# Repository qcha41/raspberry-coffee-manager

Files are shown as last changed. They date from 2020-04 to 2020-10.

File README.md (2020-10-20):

# Raspberry Coffee Manager

This is a raspberry project dedicated to the management of a shared coffee caps stock in a group through a user-friendly touchscreen interface and a RFID tag reader.

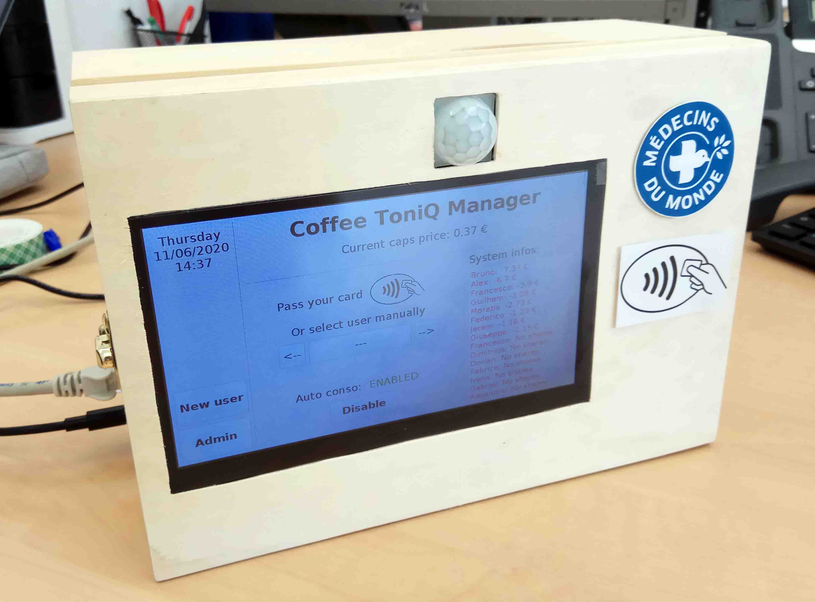
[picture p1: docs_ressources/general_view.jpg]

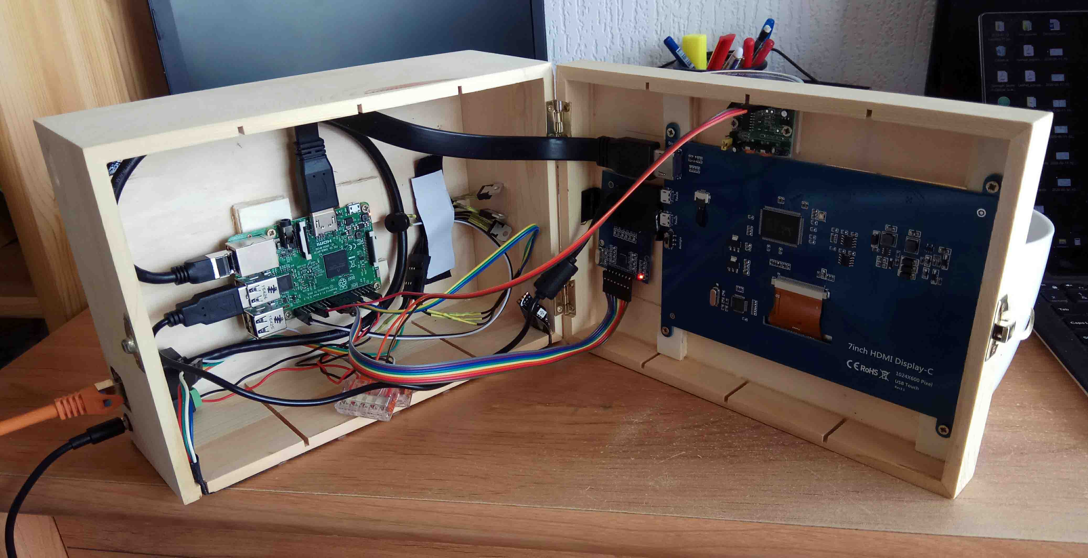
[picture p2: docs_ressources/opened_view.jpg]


## Features

- **User accounts**: The basic idea of this system is that users notify the raspberry manager each time they take a coffee caps from the group stock. This is done simply by passing their personal RFID tags near an integrated reader, or by selecting their name on the main screen. The corresponding caps price is then deducted from their personal virtual account. The users can recharge their accounts by putting some money in a common group box (or any other method decided in the group), and notify themselves this recharge in the account panel of the graphical interface. In this panel, they can also review the activity of their account day by day, change their name, link their account with another RFID tag, etc. Users also receive email notifications when their accounts are negative.

- **Admin panel**: The person in charge of managing the coffee in the group has access to a private admin panel, either by using its admin RFID tag, or by entering a password in the graphical interface. From that panel, the admin can review system operations (users recharges, ...), notify a group caps purchase, a supply purchase, or that a few caps are missing in the stock, etc.

- **Dynamical caps price**: The system thus know how many caps have been added in the stock by the admin, and how many were taken by the users. The caps price deducted from the virtual accounts is then dynamic, and is simply calculated by dividing the remaining system charges by the remaining number of caps.

- **Charities donations**: More than just managing a caps stock, this project is also a tool to raise money for charities in a group easily. In their account panel, users can indeed configure an optional automatic donation (a few cents), which is then deducted on their virtual account in addition of the caps price, each time they take a caps from the stock. In parallel, users can also proceed to manual donations in their account panel. The global amount of money raised by all users is they donated by the admin to a real charity (defined by the group), and notified in the admin panel.

- **Shares**: After having created their accounts, users are invited to add a certain amount of money in the system, as shares, in order to keep a sufficient working capital that will help the admin of the group to buy caps in advance, and to maintain a sufficiently large caps stock. Unlike the recharges, the shares do not impact in the account balance : they just act as a hidden offsets, and are refundable at any time (for instance when a user leave the group).

- **Secondary features**: The system integrates a LED strip whose the color is changing dynamically depending on the scenario (idle, green for positive balance, blinking red for negative balance..). Using a PIR sensor, the system automatically wakes up (turn on screen + led strip) when someone approaches the system, and goes back to sleep after 1 minute of inactivity.

## Screenshots

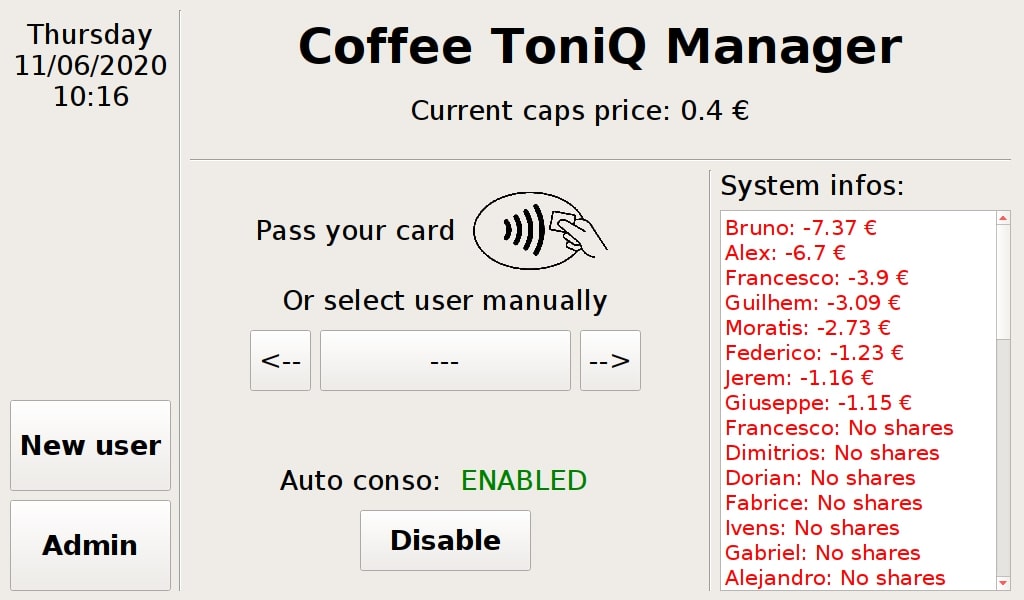
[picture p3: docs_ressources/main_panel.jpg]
<p align="center"><br><i>Main panel</i></p>
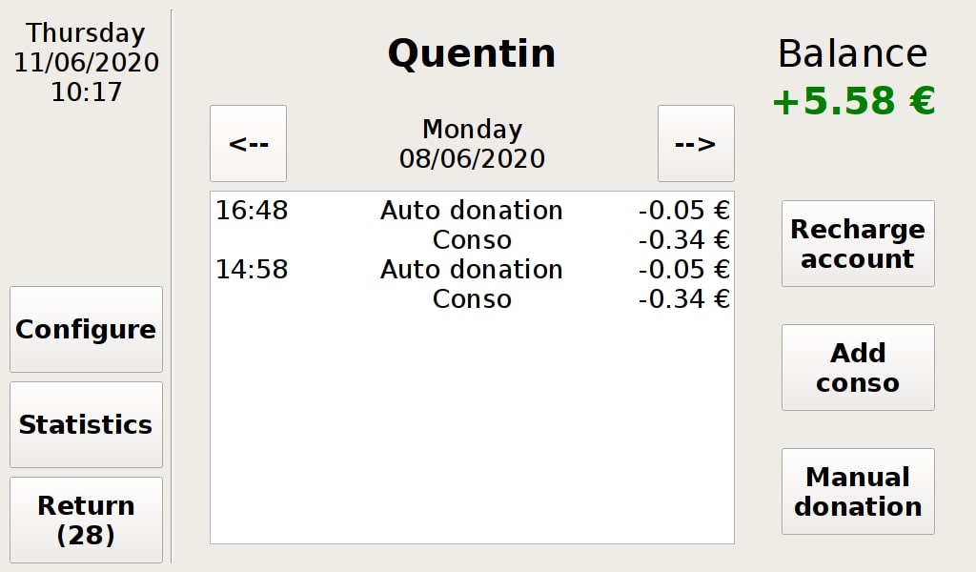
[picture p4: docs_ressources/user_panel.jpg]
<p align="center"><br><i>User account panel</i></p>
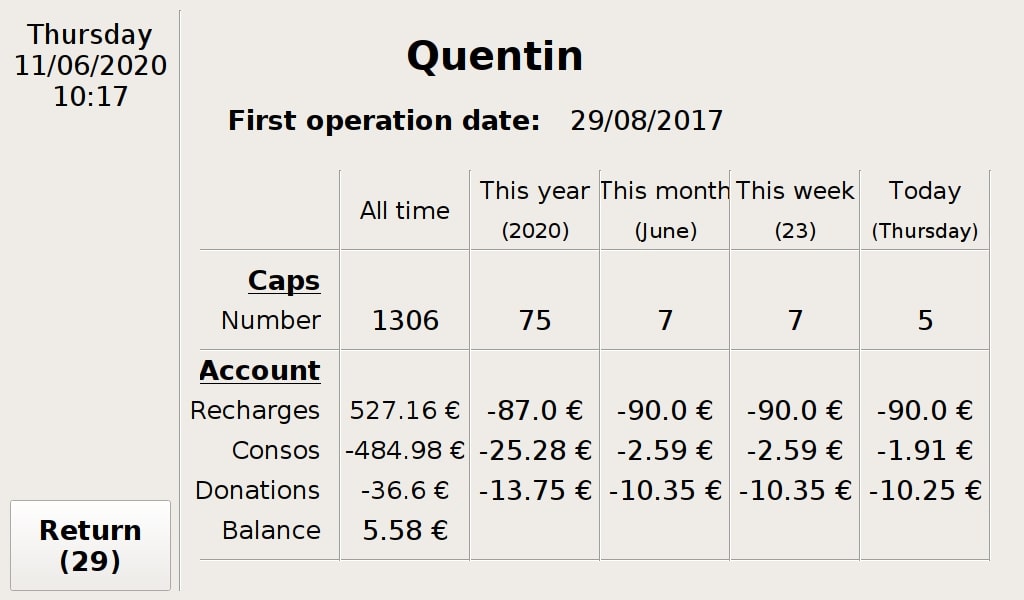
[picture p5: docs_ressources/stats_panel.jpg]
<p align="center"><br><i>User statistics panel</i></p>
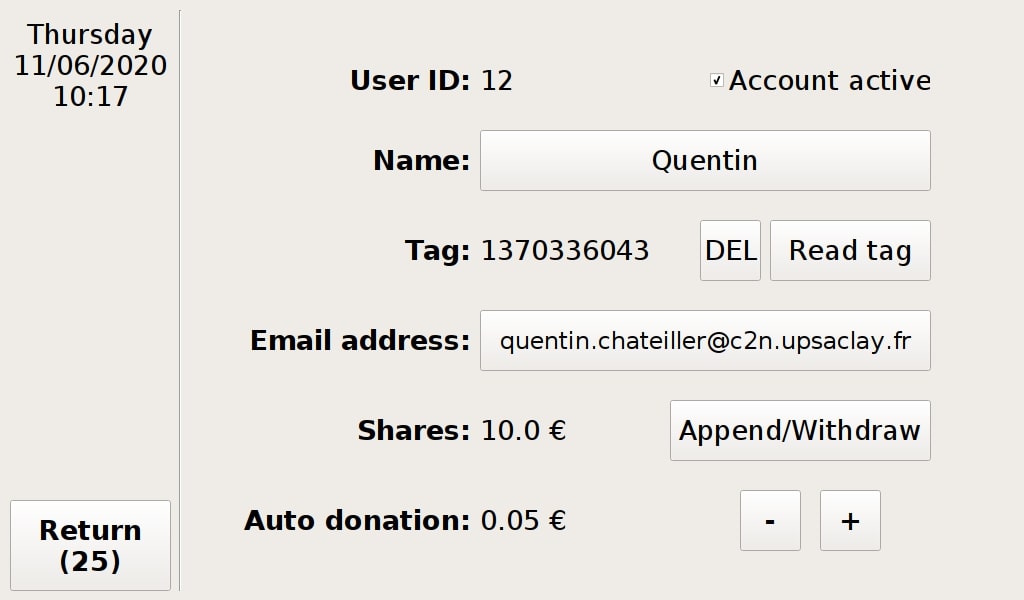
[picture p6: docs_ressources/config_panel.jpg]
<p align="center"><br><i>User configuration panel</i></p>
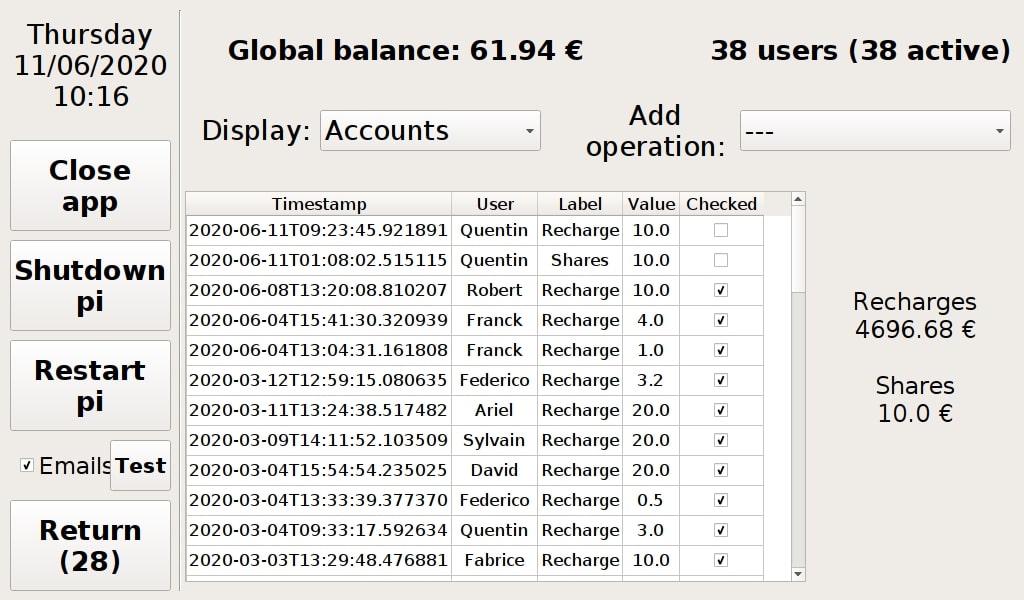
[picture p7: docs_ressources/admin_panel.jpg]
<p align="center"><br><i>Administration panel</i></p>
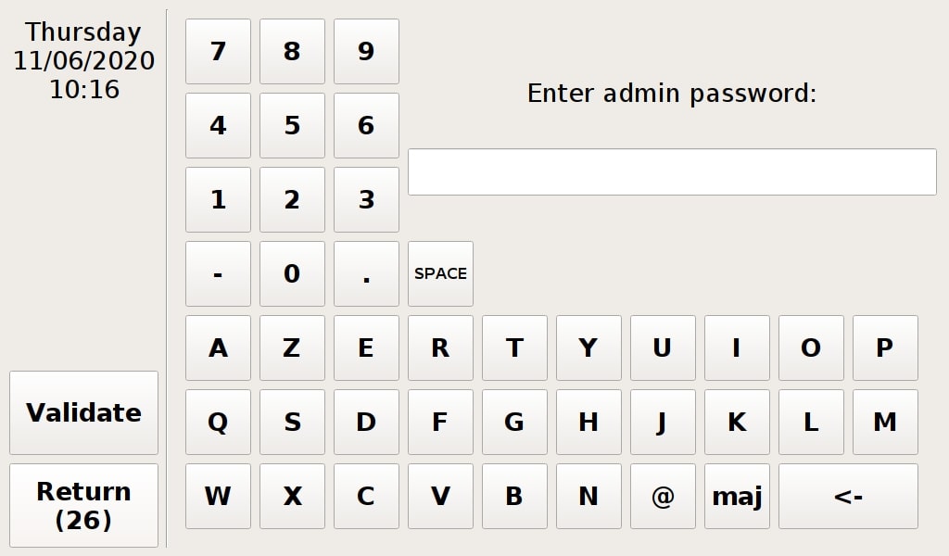
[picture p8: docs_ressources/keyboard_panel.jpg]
<p align="center"><br><i>Touchscreen keyboard</i></p>

## Technical points

- The graphical interface opens at Pi startup using cron.
- The system requires an internet connection (Ethernet/Wifi) to sync date and time (the raspberry doesn't include an RTC module).

#### Parts used

- Raspberry Pi 3B+ (https://www.raspberrypi.org/)
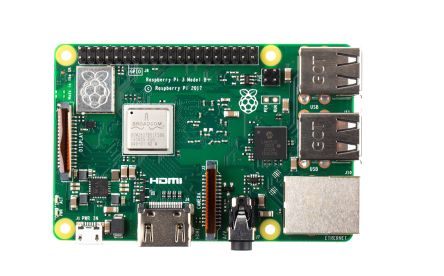
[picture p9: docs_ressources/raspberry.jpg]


- EYEWINK 7" Touchscreen 1024x600 HDMI (https://fr.aliexpress.com/item/32805673182.html)
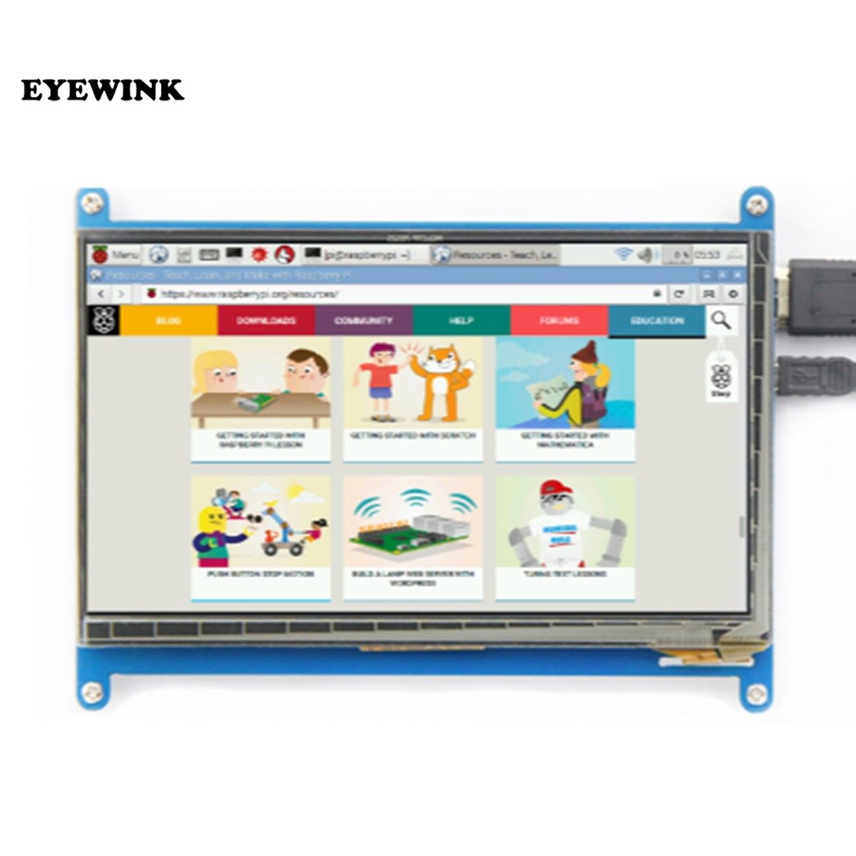
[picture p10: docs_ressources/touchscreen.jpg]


- Buzzer piezo 5V (https://fr.aliexpress.com/item/32322485389.html)
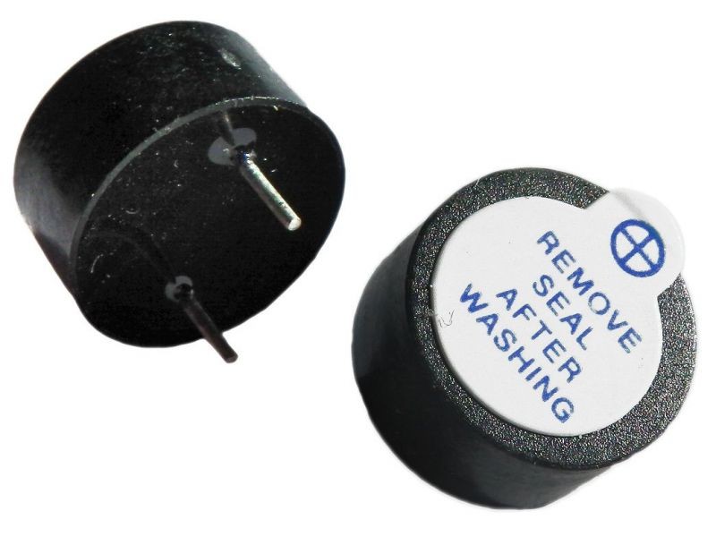
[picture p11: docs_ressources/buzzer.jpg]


- RFID module RC522 13.56 Mhz (https://fr.aliexpress.com/item/2026446641.html)
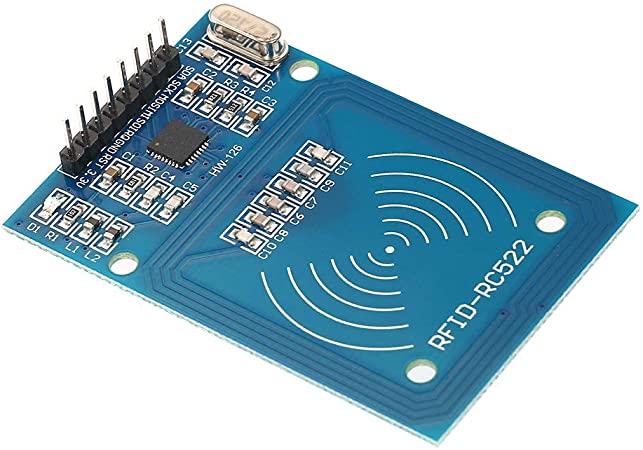
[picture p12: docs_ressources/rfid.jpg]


- RBG LED strip SMD 5050 5V (https://fr.aliexpress.com/item/32812049944.html)
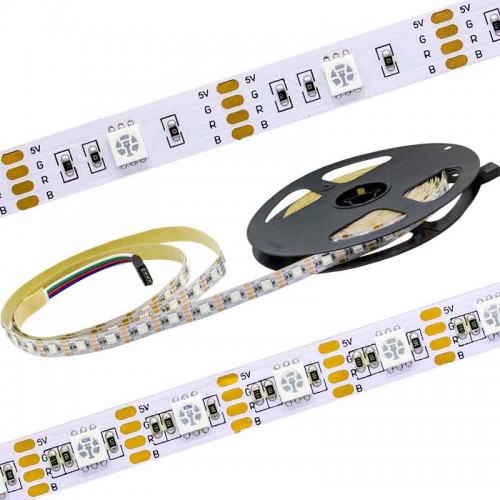
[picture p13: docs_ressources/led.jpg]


- 3 TIP120 power transistors (https://fr.aliexpress.com/item/32264482219.html)
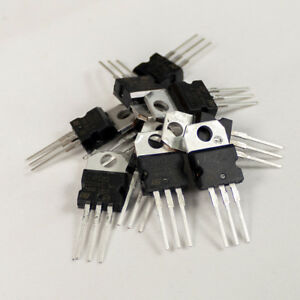
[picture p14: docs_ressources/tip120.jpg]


- PIR motion sensor HC-SR501 (https://fr.aliexpress.com/item/1874954952.html)
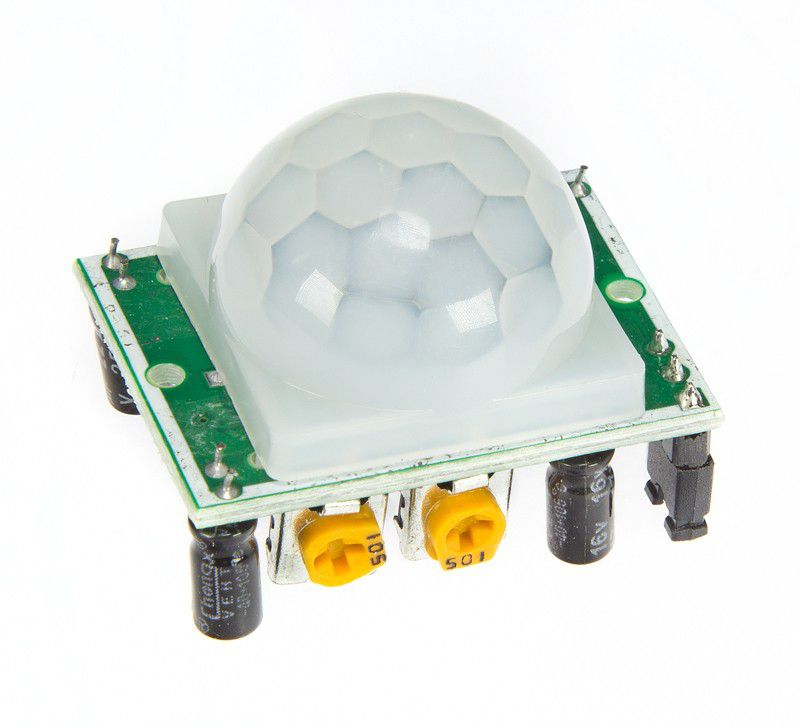
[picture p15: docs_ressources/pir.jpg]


- 5V / 3A DC power adaptor (https://www.amazon.fr/BERLS-dalimentation-Adaptateur-connecteurs-r%C3%A9sidentielle/dp/B076Y23T5Z)
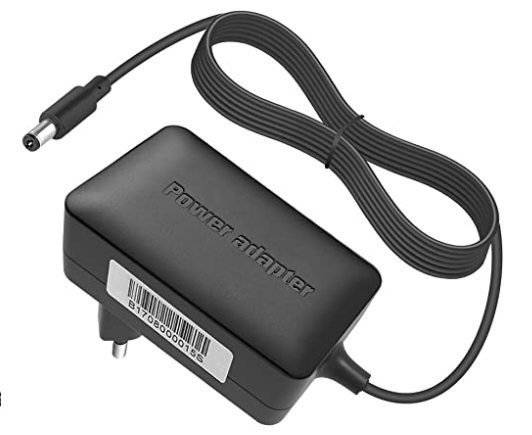
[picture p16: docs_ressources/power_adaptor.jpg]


- Female DC power connector (https://fr.aliexpress.com/item/32822006069.html)
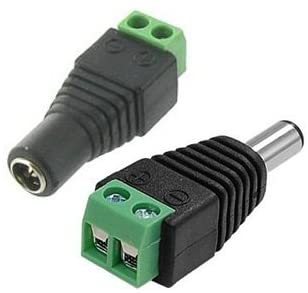
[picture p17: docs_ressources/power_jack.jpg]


- Wires

### Raspberry configuration

1. Install Python >= 3.6 (https://installvirtual.com/how-to-install-python-3-8-on-raspberry-pi-raspbian/)
2. Install python package pandas, numpy, RPi.GPIO, pi-rc522, sqlite3, pyqt5
2. Install this project
```
mkdir coffee_manager                                                  # Create main folder
git clone https://github.com/richardghirst/PiBits.git                 # Clone PiBits
git clone https://github.com/qcha41/raspberry-coffee-manager.git      # Clone GitHub project
bash raspberry-coffee-manager/install.sh                              # Auto-configuration
```

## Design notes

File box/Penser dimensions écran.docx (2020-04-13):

- Penser dimensions écran
- DC in connector
- Ethernet connector
- Trou de LED 5*5 mm, 30 LED/m → spacing = 3.333cm → 3.3cm
- Pied
- Plaquette horizontale pour fixation du pi et des transitors, buzzer.. etc
- Logo rfid

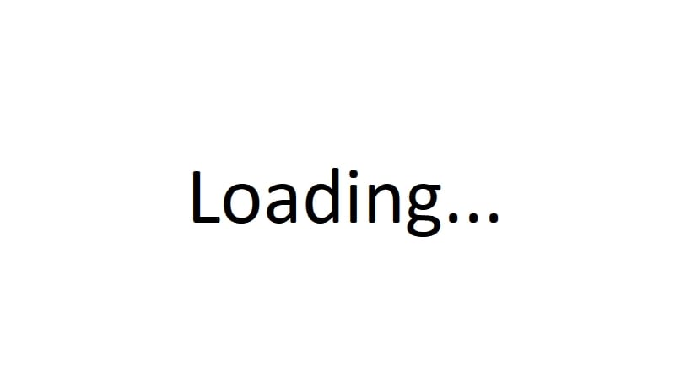
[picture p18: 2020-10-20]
docs_ressources/wallpaper.jpg

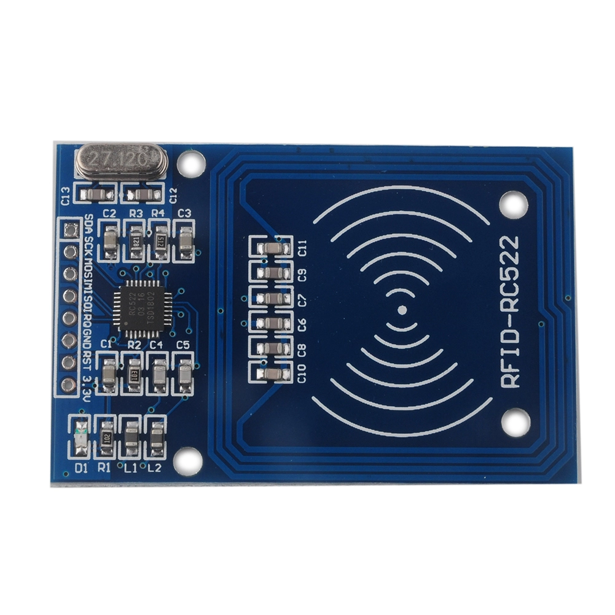
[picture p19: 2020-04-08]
docs_ressources/rfid.webp

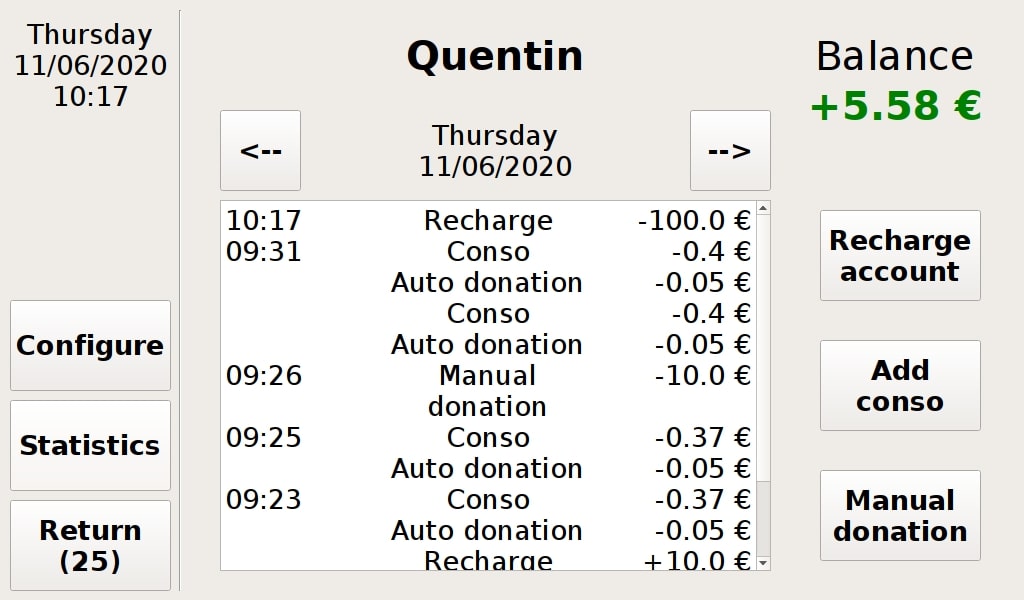
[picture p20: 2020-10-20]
docs_ressources/user_panel_2.jpg

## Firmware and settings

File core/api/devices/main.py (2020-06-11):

#!/usr/bin/env python3
# -*- coding: utf-8 -*-
"""
Created on Tue Aug 28 11:13:09 2018

@author: pi
"""



from .. import config
from .. import system 

import os

class DeviceManager():
    
    def __init__(self):
        
        from .buzzer_lib import BuzzerController
        from .led_lib import LedController
        from .pir_lib import PirSensor
        from .rfid_lib import RfidReader
        
        # Led controller
        current_script_path = os.path.realpath(os.path.dirname(__file__))
        pibits_path = os.path.join(os.path.dirname(os.path.dirname(os.path.dirname(os.path.dirname(current_script_path)))),'PiBits')

        gpio_pin_red_led = int(config['DEVICES']['gpio_pin_red_led'])
        gpio_pin_green_led = int(config['DEVICES']['gpio_pin_green_led'])
        gpio_pin_blue_led = int(config['DEVICES']['gpio_pin_blue_led'])        
        self.led = LedController(pibits_path, gpio_pin_red_led, gpio_pin_green_led, gpio_pin_blue_led)
        self.led.start()
        
        # Buzzer controller
        gpio_pin_buzzer = int(config['DEVICES']['gpio_pin_buzzer'])
        self.buzzer = BuzzerController(gpio_pin_buzzer)
        
        # PIR sensor
        gpio_pin_pir = int(config['DEVICES']['gpio_pin_pir'])
        self.pir = PirSensor(gpio_pin_pir)
        self.pir.callback = self.wake_up
        
        # RFIF reader
        self.rfid = RfidReader()
        self.rfid.start()
        
    def stop(self):
        
        self.led.stop()
        self.rfid.stop()
        
    def wake_up(self):
        
        self.led.set_idle_color('white')
        system.awake_screen()

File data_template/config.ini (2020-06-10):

[GENERAL]
system_name = Coffee Manager

[ADMIN]
tag = 25089510172
password = 0000
email = XXXXXXXXXXXXXX@gmail.com

[DONATION]
user_auto_default = 0.05
general_offset = 0

[EMAIL]
default_suffix = @XXXXXXXXXXXXXX.fr
smtp_server = smtp.gmail.com
smtp_port = 587
smtp_username = XXXXXXXXXXXXXX@gmail.com
smtp_password = XXXXXXXXXXXXXX

[DEVICES]
gpio_pin_buzzer = 40
gpio_pin_red_led = 15
gpio_pin_green_led = 16
gpio_pin_blue_led = 13
gpio_pin_pir = 31

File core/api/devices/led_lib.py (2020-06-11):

# -*- coding: utf-8 -*-
"""
Created on Wed Aug  8 19:09:21 2018

@author: qchat
"""

import os
import numpy as np
import time
from threading import Thread, Event
from queue import Queue



colors = {'red':(255,0,0),
          'green':(0,255,0),
          'white':(255,200,100),
          'orange':(255,150,0),
          'black':(0,0,0)}

class LedController(Thread):
    
    def __init__(self,pibits_path, gpio_pin_red_led, gpio_pin_green_led, gpio_pin_blue_led) :
        
        Thread.__init__(self)
        
        self.pins = {'red':gpio_pin_red_led,
                     'green':gpio_pin_green_led,
                     'blue':gpio_pin_blue_led}
        
        self.curr_scenario = 'idle'
        self.curr_color = 'black'
        self.idle_color = 'black'
        self.idle_last_change_time = time.time()
        self.idle_color_autoswitch_delay = 30 #s

        self.imax = 0.9
        self.delay_step = 0.045 #s
        
        self.queue = Queue()
        self.stop_flag = Event()

        self.pibits_path = pibits_path
        servod_folder_path = os.path.join(self.pibits_path,'ServoBlaster','user')
        os.system(f"sudo {servod_folder_path}/servod --p1pins={self.pins['red']},{self.pins['green']},{self.pins['blue']} --step-size=2us --cycle-time=5000us --min=0% --max=100%")
        
        
        
    def set_scenario(self,scenario):
        
        self.curr_scenario = scenario
        if scenario == 'idle' :
            self.ilde_last_change_time = time.time()
        
    def set_idle_color(self,color):
        self.idle_color = color
        self.ilde_last_change_time = time.time()

    def stop(self):
        self.stop_flag.set()
        self.join()

    def run(self):
        
        while self.stop_flag.is_set() is False :

            if self.curr_scenario == 'idle' :
                if self.idle_color != 'black' and (time.time()-self.idle_last_change_time)>self.idle_color_autoswitch_delay :
                    self.idle_color = 'black'
                self.apply_color(self.idle_color,0.5)
            if self.curr_scenario == 'fixed_green' :
                self.apply_color('green',0.5)
            if self.curr_scenario == 'low_blinking_orange' :
                self.apply_color('orange', 1.5) 
                self.apply_color('black',1.5) 
            if self.curr_scenario == 'high_blinking_red' :
                self.apply_color('red',0.2) 
                self.apply_color('black',0.2)
            
    
    

    def apply_color(self,color,delay):
                
        if color == self.curr_color :
            time.sleep(delay)
            
        else :             
            (curr_r,curr_g,curr_b) = colors[self.curr_color]
            (new_r,new_g,new_b) = colors[color]
            
            # Setup sequence
            nb_pts = int(round(delay / self.delay_step)+2)
            r_list = np.linspace(curr_r,new_r,nb_pts)
            g_list = np.linspace(curr_g,new_g,nb_pts)
            b_list = np.linspace(curr_b,new_b,nb_pts)
            
            # Execute sequence
            for i in range(len(r_list)) :
                tini = time.time()
                command = ''
                command += f"echo P1-{self.pins['red']}={round(self.imax*r_list[i]/255*100,2)}% > /dev/servoblaster;"
                command += f"echo P1-{self.pins['green']}={round(self.imax*g_list[i]/255*100,2)}% > /dev/servoblaster;"
                command += f"echo P1-{self.pins['blue']}={round(self.imax*b_list[i]/255*100,2)}% > /dev/servoblaster;"
                os.system(command)
                try : time.sleep(self.delay_step-(time.time()-tini)) #may be negative some times
                except : pass
            
            # Save last state
            self.curr_color = color

        

        
if __name__ == '__main__' :
    
    pibits_path = ''
    gpio_pin_red_led = 15
    gpio_pin_green_led = 16
    gpio_pin_blue_led = 13
    
    led = LedController(pibits_path, gpio_pin_red_led, gpio_pin_green_led, gpio_pin_blue_led)
    led.set_scenario('high_blinking_red')
    time.sleep(3)
    led.set_scenario('high_blinking_red')
    
 
        

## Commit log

2020-04-09 update dics ressources
    [scheme.fzz]
2020-04-09 raw devices integration in gui
2020-04-11 threadmonitoring moved
2020-04-13 terminate devices threads when stopEvent detected
